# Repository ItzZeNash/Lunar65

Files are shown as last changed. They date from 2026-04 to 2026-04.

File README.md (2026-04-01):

# Lunar65
A keyboard made for personal use and sounds good, as I dont have a keyboard. 65% for optimal usability.
Render/Image

Images of Schem And PCB



# Build Guide










| No | Name | Spec | Quantity |
| ----- | ----- | ----- | ----- |
| 1 | Aluminum case | Aluminum | 1 |
| 2 | Main PCB | Hotswap socket compatible, 1.6 mm thick | 1 |
| 3 | Plate | Polycarbonate, 1.5mm thick | 1 |
| 4 | PCB foam | Poron, 3mm thick | 1 |
| 5 | Switch foam | Polyethylene or Poron, 0.5mm thick | 1 |
| 6 | Case foam | Poron, 1.5mm thick | 1 |
| 7 | Socket foam | Poron, 1.5mm thick | 1 |
| 8 | O-ring | AS568-264-VMQ-A30 | 1 |
| 9 | USB-C daughter board | [Unified Daughterboard C3](https://github.com/ai03-2725/Unified-Daughterboard) | 1 |
| 10 | JST cable | JST-SH, 4pin, double-side female connector, reverse direction, 10cm | 1 |
| 11 | Screws | m2 4mm, for USB-C daughter board | 4 |
| 12 | Rubber feet(Bumpons) | 3M SJ5302, diameter 8mm, height 2mm | 4 |

### Parts
| Name | Spec | Quantity |
| ----- | ----- | ----- |
| Key switch | CherryMX compatible key switch, 5pins(recommended) | 67 |
| Keycap | CherryMX compatible keycap, 1.75U Shift key(required) | 67 |
| Stabilizer | Durock V2, etc | 6.25U * 1set and 2U * 3set |
| USB cable | The connector on the keyboard side must be USB-C | 1 |
| Grease for lubrication | Krytox 205g0(recommended) | a few grams |

## Assembly Instructions
1. **Attaching rubber feet**  
   Rubber feet
   First attach the rubber feet to the aluminum case so that the bottom of the aluminum case is not scratched.  
   Attach the rubber feet according to the engraved circle on the four corners of the back of the aluminum case.  

1. **Pasting socket foam**  
   Pasting socket foam
   Pasting socket foam is difficult and cannot be redone.  
   There are two methods: one is to paste the entire surface and the other is to paste only a portion of the surface.  
   
   **Practice**  
   First, practice several times without peeling off the release paper on the adhesive surface.  
   Pasting socket foam
   Place the socket foam on a flat surface with the adhesive surface facing up.  
   Straighten any bent or floating parts.  
   Pasting socket foam
   Hold the four corners with the back side (part mounting surface) of the main PCB facing down.  
   Look at the main PCB from directly above, align the notch of the mount post with the main PCB, slowly put it on the foam.  

   **When pasting the entire surface**  
   Peel off the release paper on the socket foam, and paste the main PCB and socket foam according to the procedure you practiced.  
   Once pasted, it cannot be removed cleanly, so recommend not removing it, even if it is slightly displaced.  
   (even if it can be removed, the socket foam will be stretched and the position will not match)  
   
   **When pasting only a part**  
   Peel off only a part of the release paper and paste it.  
   The area to peel off is about 10 square mm per place, and the place to peel off is about 7-8 places where the width is not narrow.  
   Cut a part of the release paper with scissors and paste the main PCB and socket foam according to the procedure you practiced.

1. **Assembling the stabilizers**  
   Please refer to [this YouTube video](https://www.youtube.com/watch?v=-vhpHjlkRgQ).  
   Apply a little thick grease to the outside of the stem and the inside of the housing.  
   Insert the stem into the housing.  
   Apply a little thick grease from the tip of the wire to the part that bends at a right angle.  
   Insert the wire into the stem and fit the wire into the housing.  

1. **Installing stabilizers**  
   Installing stabilizers
   First, insert the side without screw holes into the larger stabilizer mounting holes on the main PCB.  
   Next, screw the side with screw holes from the back side of the main PCB.  
   Make sure that the stabilizer housing is not lifted off the main PCB and that there is no rattling.  

1. **Placing switch foam**  
   Placing switch foam
   Place the switch foam on the main PCB.  
   Slide the switch foam so that it is under the stabilizer wires.  

1. **Placing PCB foam**  
   Placing PCB foam
   Place PCB foam on the main PCB in line with the stabilizer position.  

1. **Placing plate**
   Placing plate
   Place the plate on the PCB foam, aligning it with the hole in the key switches.  

1. **Lubricating key switches**  
   Although not required, it is highly recommended to lubricate the key switches to improve the typing feels and sounds.  
   Please refer to [this YouTube video](https://www.youtube.com/watch?v=44Wv4OGdmu4).  

1. **Installing key switches**  
   Installing key switches
   Check that the holes in the switch foam align with the key switch pin holes on the main PCB.  
   Check that the pins of the key switch are straight and insert the key switch into the main PCB from the top of the plate.  
   (Be careful not to insert at an angle, as this may break the pins or damage the sockets)  
   Make sure that there are no gaps between the plate and the key switches, and between the key switches and the main PCB, viewed from the side, and that they are evenly installed.  

1. **Installing O-ring**  
   Install O-ring between main PCB and plate.  
   Installing O-ring
   
   Around the backspace and spacebar keys, pass the O-ring through the top surface of the stabilizer, aligning it with the notch in the plate.  
   If the O-ring cannot be secured to the top of the stabilizer, proceed as is once it is in place, as it can be adjusted when the main PCB is installed in the case.  
   Make sure there is no gap and bend between the main PCB, O-ring and plate when viewed from the side.  

1. **Connecting JST cable to USB-C daughter board**  
   Connecting JST cable to USB-C daughter board
   Connect JST cable to USB-C daughter board.  
   Connecting JST cable to USB-C daughter board
   Since JST cable connectors have front and back sides, refer to the photo and insert the connector with the side with no exposed terminals facing up.    

1. **Installing USB-C daughter board**  
   Installing USB-C daughter board
   With the surface of the USB-C daughter board (the side where the components are mounted) facing up, screw it into the center back of the aluminum case with four m2 4mm screws.  
   Grab the screws with tweezers to make it easier to screw them in.  

1. **Installing case foam**  
   Installing case foam
   Align the posts inside the aluminum case with the notches in the case foam, and put the case foam inside the aluminum case.    
   Pull the JST cable through the cutout in the case foam.  

1. **Connecting JST cable tom main PCB**  
   Connecting JST cable tom main PCB
   Insert the JST cable connector into the JST connector (beige color) on the back of the main PCB.  
   Connecting JST cable tom main PCB
   Since JST cable connectors have front and back sides, refer to the photo and insert the connector with the side with no exposed terminals facing up.    

1. **Installing main PCB to aluminum case**  
   Installing main PCB to aluminum case
   With the back side of the main PCB slightly raised, pass the blocker of the aluminum case between the blocker of the main PCB and the O-ring.    
   Lift the entire main PCB slightly and put the O-ring on the front side of the main PCB over the post on the front side of the aluminum case (not visible).  
   Gently push the main PCB down until the O-ring lightly touches the post on the aluminum case (not visible).  
   O-ring and back space
   Make sure the O-ring is not rolled up and coming out of  the plate.  

1. **Installing keycaps**  
   Installing keycaps
   Installing the keycaps to the key switches.  

1. **Connecting USB cable**  
   Connecting USB cable
   Connect your USB cable to the keyboard and PC and now it is completed.

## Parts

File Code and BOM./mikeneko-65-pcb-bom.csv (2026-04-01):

Designator | Comment | Footprint | LCSC Part #
C1 C2 C3 | 0.1u | Capacitor_SMD:C_0805_2012Metric | C49678
C4 | 10u | Capacitor_SMD:C_0805_2012Metric | C15850
C5 C6 | 22p | Capacitor_SMD:C_0805_2012Metric | C1804
C7 | 1u | Capacitor_SMD:C_0805_2012Metric | C28323
D1 D2 D3 D4 D5 D6 D7 D8 D9 D10 D11 D12 D13 D14 D15 D16 D17 D18 D19 D20 D21 D22 D23 D24 D25 D26 D27 D28 D29 D30 D31 D32 D33 D34 D35 D36 D37 D38 D39 D40 D41 D42 D43 D44 D45 D46 D47 D48 D49 D50 D51 D52 D53 D54 D55 D56 D57 D58 D59 D60 D61 D62 D63 D64 D65 D66 D67 | 1N4148 | Diode_SMD:D_SOD-123 | C81598
F1 | 500mA | Fuse:Fuse_1206_3216Metric | C70076
J1 | JST SH 4-pin | Connector_JST:JST_SH_SM04B-SRSS-TB_1x04-1MP_P1.00mm_Horizontal | C145956
MX1 MX2 MX3 MX4 MX5 MX6 MX7 MX8 MX9 MX10 MX11 MX12 MX13 MX15 MX17 MX18 MX19 MX20 MX21 MX22 MX23 MX24 MX25 MX26 MX27 MX28 MX30 MX32 MX33 MX34 MX35 MX36 MX37 MX38 MX39 MX40 MX41 MX42 MX44 MX46 MX47 MX48 MX49 MX50 MX51 MX52 MX53 MX54 MX55 MX57 MX58 MX65 MX66 MX67 | 1u | MX_Only:MXOnly-1U-Hotswap | C2803348
MX14 | 2u | MX_Only:MXOnly-2U-Hotswap | C2803348
MX16 MX29 | 1.5u | MX_Only:MXOnly-1.5U-Hotswap | C2803348
MX31 MX56 | 1.75u | MX_Only:MXOnly-1.75U-Hotswap | C2803348
MX43 MX45 | 2.25u | MX_Only:MXOnly-2.25U-Hotswap | C2803348
MX59 MX60 MX61 MX63 MX64 | 1.25u | MX_Only:MXOnly-1.25U-Hotswap | C2803348
MX62 | 6.25u | MX_Only:MXOnly-6.25U-Hotswap-ReversedStabilizers | C2803348
R1 R4 | 10k | Resistor_SMD:R_0805_2012Metric | C17414
R2 R3 | 22 | Resistor_SMD:R_0805_2012Metric | C17561
SW1 | Reset | Button_Switch_SMD:SW_SPST_TL3342 | C318884
U1 | SRV05-4 | Package_TO_SOT_SMD:SOT-23-6 | C85364
U2 | ATmega32U4-MUR | Package_DFN_QFN:QFN-44-1EP_7x7mm_P0.5mm_EP5.2x5.2mm | C45874
Y1 | 16MHz | Crystal:Crystal_SMD_3225-4Pin_3.2x2.5mm | C13738

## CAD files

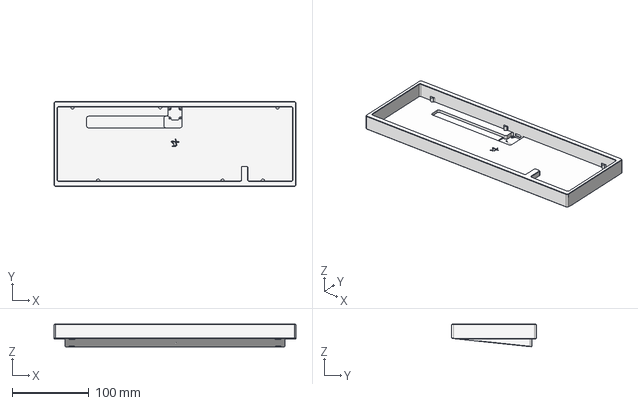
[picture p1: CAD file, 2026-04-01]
Case Files/セ-65-case.step
314.8 x 110.2 x 29.4 mm

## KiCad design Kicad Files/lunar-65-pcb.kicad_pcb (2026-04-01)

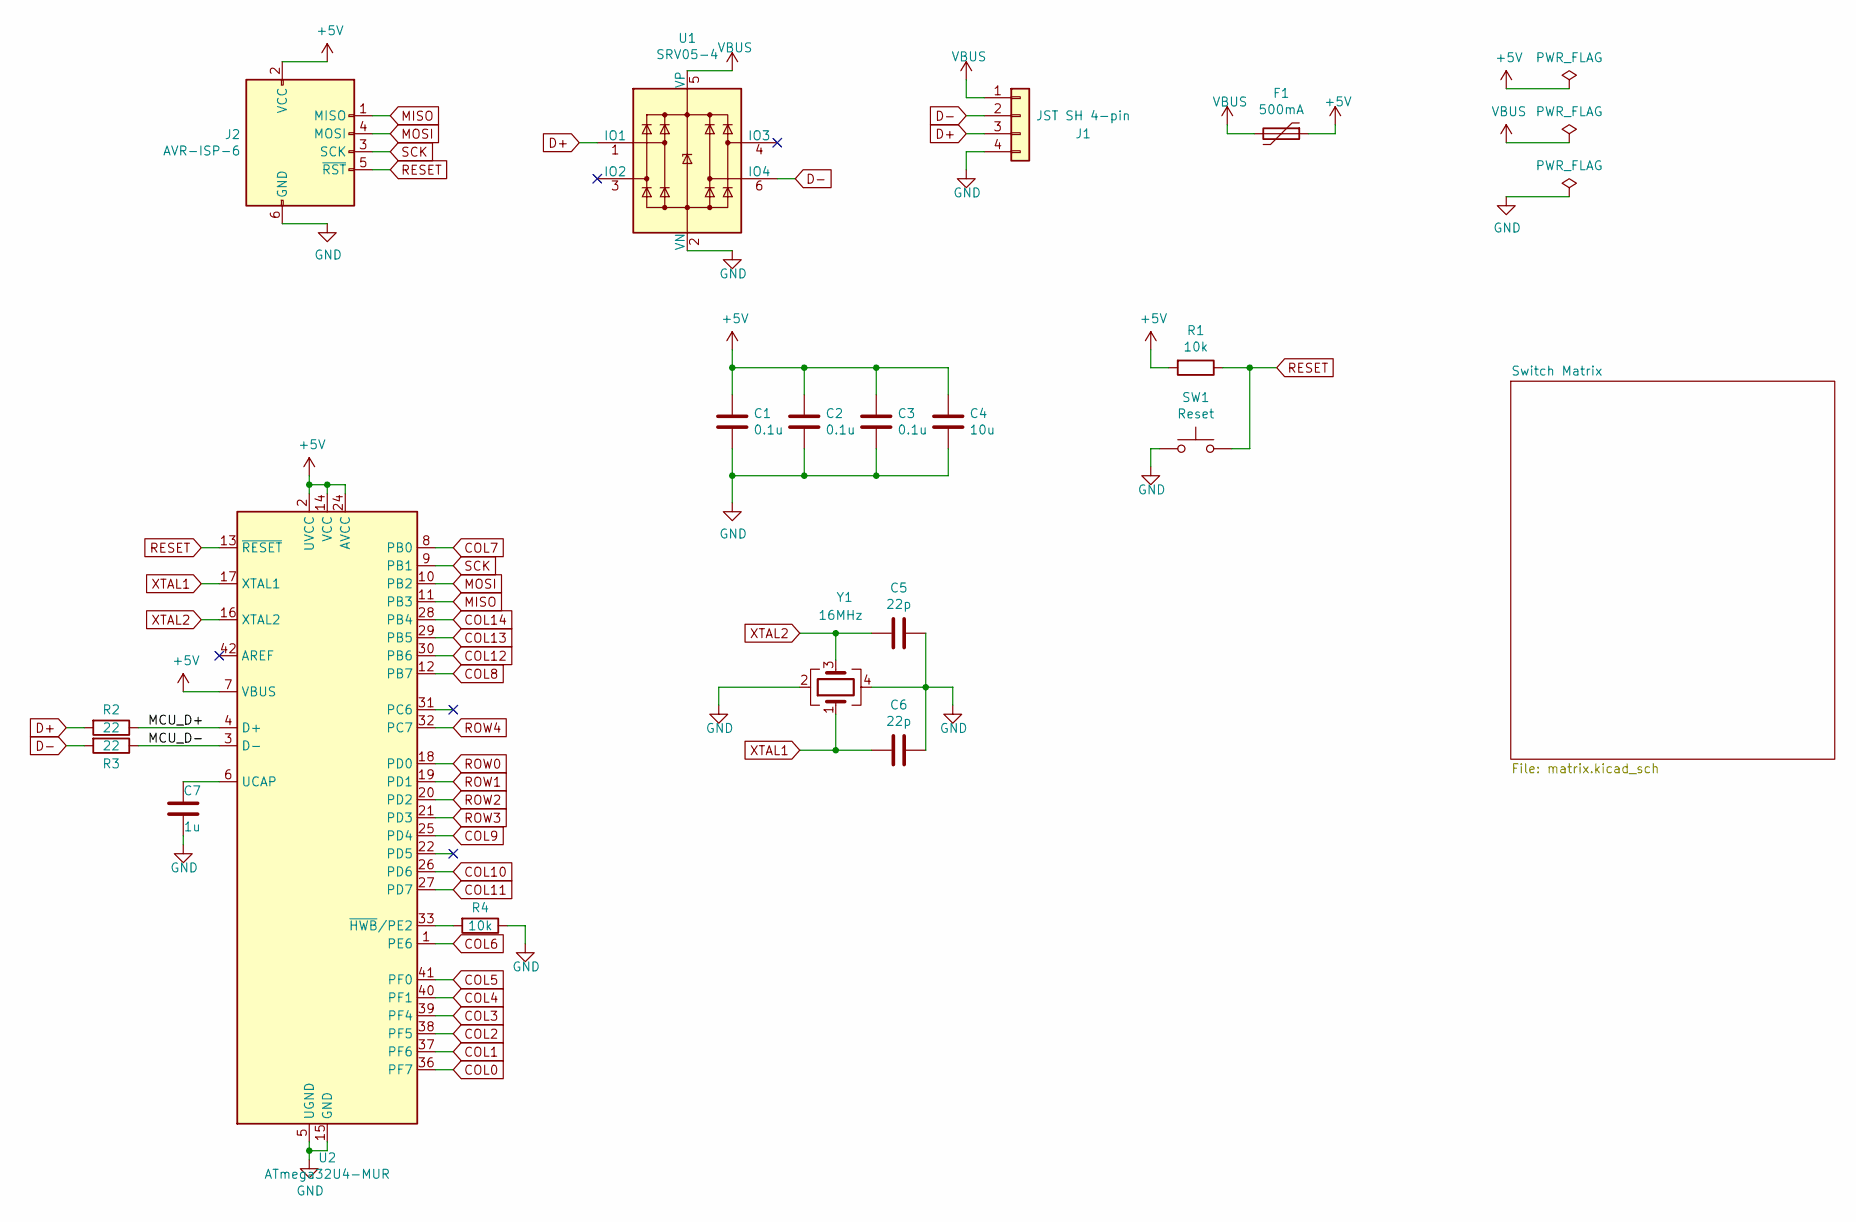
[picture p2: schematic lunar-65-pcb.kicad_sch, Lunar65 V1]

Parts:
C1, C2, C3: 0.1u; C_0805_2012Metric; LCSC Part # C49678
C4: 10u; C_0805_2012Metric; LCSC Part # C15850
C5, C6: 22p; C_0805_2012Metric; LCSC Part # C1804
C7: 1u; C_0805_2012Metric; LCSC Part # C28323
F1: 500mA; Fuse_1206_3216Metric; LCSC Part # C70076
J1: JST SH 4-pin; JST_SH_SM04B-SRSS-TB_1x04-1MP_P1.00mm_Horizontal; LCSC Part # C145956
J2: AVR-ISP-6; ISP
R1, R4: 10k; R_0805_2012Metric; LCSC Part # C17414
R2, R3: 22; R_0805_2012Metric; LCSC Part # C17561
SW1: Reset; SW_SPST_TL3342; LCSC Part # C318884
U1: SRV05-4; SOT-23-6; LCSC Part # C85364
U2: ATmega32U4-MUR; QFN-44-1EP_7x7mm_P0.5mm_EP5.2x5.2mm; LCSC Part # C45874
Y1: 16MHz; Crystal_SMD_3225-4Pin_3.2x2.5mm; LCSC Part # C13738

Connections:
+5V: C1.1, C2.1, C3.1, C4.1, F1.1, J2.2 (VCC), R1.2, U2.2 (UVCC), U2.7 (VBUS), U2.14 (VCC), U2.24 (AVCC), U2.34 (VCC), U2.44 (AVCC)
/MCU_D+: R2.1, U2.4 (D+)
/MCU_D-: R3.1, U2.3 (D-)
COL0: U2.36 (PF7); also elsewhere on the board
COL1: U2.37 (PF6); also elsewhere on the board
COL2: U2.38 (PF5); also elsewhere on the board
COL3: U2.39 (PF4); also elsewhere on the board
COL4: U2.40 (PF1); also elsewhere on the board
COL5: U2.41 (PF0); also elsewhere on the board
COL6: U2.1 (PE6); also elsewhere on the board
COL7: U2.8 (PB0); also elsewhere on the board
COL8: U2.12 (PB7); also elsewhere on the board
COL9: U2.25 (PD4); also elsewhere on the board
COL10: U2.26 (PD6); also elsewhere on the board
COL11: U2.27 (PD7); also elsewhere on the board
COL12: U2.30 (PB6); also elsewhere on the board
COL13: U2.29 (PB5); also elsewhere on the board
COL14: U2.28 (PB4); also elsewhere on the board
D+: J1.3, R2.2, U1.1 (IO1)
D-: J1.2, R3.2, U1.6 (IO4)
GND: C1.2, C2.2, C3.2, C4.2, C5.1, C6.1, C7.2, J1.4, J2.6 (GND), R4.1, SW1.1, U1.2 (VN), U2.5 (UGND), U2.15 (GND), U2.23 (GND), U2.35 (GND), U2.43 (GND), U2.45 (GND), Y1.2, Y1.4
MISO: J2.1 (MISO), U2.11 (PB3)
MOSI: J2.4 (MOSI), U2.10 (PB2)
unnamed: C7.1, U2.6 (UCAP)
unnamed: R4.2, U2.33 (~HWB/PE2)
RESET: J2.5 (~RST), R1.1, SW1.2, U2.13 (~RESET)
ROW0: U2.18 (PD0); also elsewhere on the board
ROW1: U2.19 (PD1); also elsewhere on the board
ROW2: U2.20 (PD2); also elsewhere on the board
ROW3: U2.21 (PD3); also elsewhere on the board
ROW4: U2.32 (PC7); also elsewhere on the board
SCK: J2.3 (SCK), U2.9 (PB1)
VBUS: F1.2, J1.1, U1.5 (VP)
XTAL1: C6.2, U2.17 (XTAL1), Y1.1
XTAL2: C5.2, U2.16 (XTAL2), Y1.3

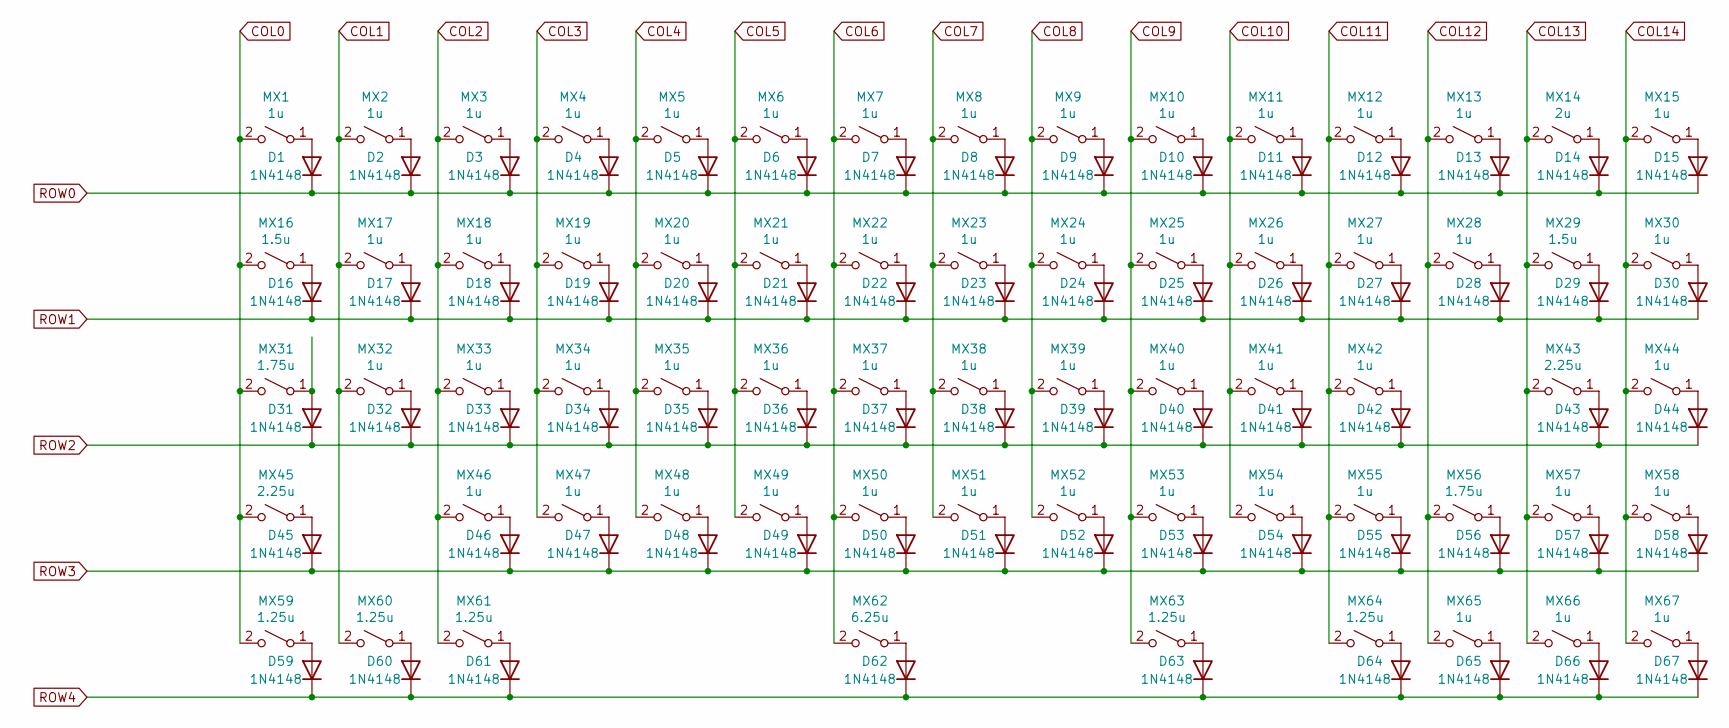
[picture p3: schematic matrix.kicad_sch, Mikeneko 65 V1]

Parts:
D1, D2, D3, D4, D5, D6, D7, D8, D9, D10, D11, D12, D13, D14, D15, D16, D17, D18, D19, D20, D21, D22, D23, D24, D25, D26, D27, D28, D29, D30, D31, D32, D33, D34, D35, D36, D37, D38, D39, D40, D41, D42, D43, D44, D45, D46, D47, D48, D49, D50, D51, D52, D53, D54, D55, D56, D57, D58, D59, D60, D61, D62, D63, D64, D65, D66, D67: 1N4148; D_SOD-123; LCSC Part # C81598
MX1, MX2, MX3, MX4, MX5, MX6, MX7, MX8, MX9, MX10, MX11, MX12, MX13, MX15, MX17, MX18, MX19, MX20, MX21, MX22, MX23, MX24, MX25, MX26, MX27, MX28, MX30, MX32, MX33, MX34, MX35, MX36, MX37, MX38, MX39, MX40, MX41, MX42, MX44, MX46, MX47, MX48, MX49, MX50, MX51, MX52, MX53, MX54, MX55, MX57, MX58, MX65, MX66, MX67: 1u; MXOnly-1U-Hotswap; LCSC Part # C2803348
MX14: 2u; MXOnly-2U-Hotswap; LCSC Part # C2803348
MX16, MX29: 1.5u; MXOnly-1.5U-Hotswap; LCSC Part # C2803348
MX31, MX56: 1.75u; MXOnly-1.75U-Hotswap; LCSC Part # C2803348
MX43, MX45: 2.25u; MXOnly-2.25U-Hotswap; LCSC Part # C2803348
MX59, MX60, MX61, MX63, MX64: 1.25u; MXOnly-1.25U-Hotswap; LCSC Part # C2803348
MX62: 6.25u; MXOnly-6.25U-Hotswap-ReversedStabilizers; LCSC Part # C2803348

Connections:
COL0: MX1.2 (B), MX16.2 (B), MX31.2 (B), MX45.2 (B), MX59.2 (B); also elsewhere on the board
COL1: MX2.2 (B), MX17.2 (B), MX32.2 (B), MX60.2 (B); also elsewhere on the board
COL2: MX3.2 (B), MX18.2 (B), MX33.2 (B), MX46.2 (B), MX61.2 (B); also elsewhere on the board
COL3: MX4.2 (B), MX19.2 (B), MX34.2 (B), MX47.2 (B); also elsewhere on the board
COL4: MX5.2 (B), MX20.2 (B), MX35.2 (B), MX48.2 (B); also elsewhere on the board
COL5: MX6.2 (B), MX21.2 (B), MX36.2 (B), MX49.2 (B); also elsewhere on the board
COL6: MX7.2 (B), MX22.2 (B), MX37.2 (B), MX50.2 (B), MX62.2 (B); also elsewhere on the board
COL7: MX8.2 (B), MX23.2 (B), MX38.2 (B), MX51.2 (B); also elsewhere on the board
COL8: MX9.2 (B), MX24.2 (B), MX39.2 (B), MX52.2 (B); also elsewhere on the board
COL9: MX10.2 (B), MX25.2 (B), MX40.2 (B), MX53.2 (B), MX63.2 (B); also elsewhere on the board
COL10: MX11.2 (B), MX26.2 (B), MX41.2 (B), MX54.2 (B); also elsewhere on the board
COL11: MX12.2 (B), MX27.2 (B), MX42.2 (B), MX55.2 (B), MX64.2 (B); also elsewhere on the board
COL12: MX13.2 (B), MX28.2 (B), MX56.2 (B), MX65.2 (B); also elsewhere on the board
COL13: MX14.2 (B), MX29.2 (B), MX43.2 (B), MX57.2 (B), MX66.2 (B); also elsewhere on the board
COL14: MX15.2 (B), MX30.2 (B), MX44.2 (B), MX58.2 (B), MX67.2 (B); also elsewhere on the board
unnamed: D1.2 (A), MX1.1 (A)
unnamed: D2.2 (A), MX2.1 (A)
unnamed: D3.2 (A), MX3.1 (A)
unnamed: D4.2 (A), MX4.1 (A)
unnamed: D5.2 (A), MX5.1 (A)
unnamed: D6.2 (A), MX6.1 (A)
unnamed: D7.2 (A), MX7.1 (A)
unnamed: D8.2 (A), MX8.1 (A)
unnamed: D9.2 (A), MX9.1 (A)
unnamed: D10.2 (A), MX10.1 (A)
unnamed: D11.2 (A), MX11.1 (A)
unnamed: D12.2 (A), MX12.1 (A)
unnamed: D13.2 (A), MX13.1 (A)
unnamed: D14.2 (A), MX14.1 (A)
unnamed: D15.2 (A), MX15.1 (A)
unnamed: D16.2 (A), MX16.1 (A)
unnamed: D17.2 (A), MX17.1 (A)
unnamed: D18.2 (A), MX18.1 (A)
unnamed: D19.2 (A), MX19.1 (A)
unnamed: D20.2 (A), MX20.1 (A)
unnamed: D21.2 (A), MX21.1 (A)
unnamed: D22.2 (A), MX22.1 (A)
unnamed: D23.2 (A), MX23.1 (A)
unnamed: D24.2 (A), MX24.1 (A)
unnamed: D25.2 (A), MX25.1 (A)
unnamed: D26.2 (A), MX26.1 (A)
unnamed: D27.2 (A), MX27.1 (A)
unnamed: D28.2 (A), MX28.1 (A)
unnamed: D29.2 (A), MX29.1 (A)
unnamed: D30.2 (A), MX30.1 (A)
unnamed: D31.2 (A), MX31.1 (A)
unnamed: D32.2 (A), MX32.1 (A)
unnamed: D33.2 (A), MX33.1 (A)
unnamed: D34.2 (A), MX34.1 (A)
unnamed: D35.2 (A), MX35.1 (A)
unnamed: D36.2 (A), MX36.1 (A)
unnamed: D37.2 (A), MX37.1 (A)
unnamed: D38.2 (A), MX38.1 (A)
unnamed: D39.2 (A), MX39.1 (A)
unnamed: D40.2 (A), MX40.1 (A)
unnamed: D41.2 (A), MX41.1 (A)
unnamed: D42.2 (A), MX42.1 (A)
unnamed: D43.2 (A), MX43.1 (A)
unnamed: D44.2 (A), MX44.1 (A)
unnamed: D45.2 (A), MX45.1 (A)
unnamed: D46.2 (A), MX46.1 (A)
unnamed: D47.2 (A), MX47.1 (A)
unnamed: D48.2 (A), MX48.1 (A)
unnamed: D49.2 (A), MX49.1 (A)
unnamed: D50.2 (A), MX50.1 (A)
unnamed: D51.2 (A), MX51.1 (A)
unnamed: D52.2 (A), MX52.1 (A)
unnamed: D53.2 (A), MX53.1 (A)
unnamed: D54.2 (A), MX54.1 (A)
unnamed: D55.2 (A), MX55.1 (A)
unnamed: D56.2 (A), MX56.1 (A)
unnamed: D57.2 (A), MX57.1 (A)
unnamed: D58.2 (A), MX58.1 (A)
unnamed: D59.2 (A), MX59.1 (A)
unnamed: D60.2 (A), MX60.1 (A)
unnamed: D61.2 (A), MX61.1 (A)
unnamed: D62.2 (A), MX62.1 (A)
unnamed: D63.2 (A), MX63.1 (A)
unnamed: D64.2 (A), MX64.1 (A)
unnamed: D65.2 (A), MX65.1 (A)
unnamed: D66.2 (A), MX66.1 (A)
unnamed: D67.2 (A), MX67.1 (A)
ROW0: D1.1 (K), D2.1 (K), D3.1 (K), D4.1 (K), D5.1 (K), D6.1 (K), D7.1 (K), D8.1 (K), D9.1 (K), D10.1 (K), D11.1 (K), D12.1 (K), D13.1 (K), D14.1 (K), D15.1 (K); also elsewhere on the board
ROW1: D16.1 (K), D17.1 (K), D18.1 (K), D19.1 (K), D20.1 (K), D21.1 (K), D22.1 (K), D23.1 (K), D24.1 (K), D25.1 (K), D26.1 (K), D27.1 (K), D28.1 (K), D29.1 (K), D30.1 (K); also elsewhere on the board
ROW2: D31.1 (K), D32.1 (K), D33.1 (K), D34.1 (K), D35.1 (K), D36.1 (K), D37.1 (K), D38.1 (K), D39.1 (K), D40.1 (K), D41.1 (K), D42.1 (K), D43.1 (K), D44.1 (K); also elsewhere on the board
ROW3: D45.1 (K), D46.1 (K), D47.1 (K), D48.1 (K), D49.1 (K), D50.1 (K), D51.1 (K), D52.1 (K), D53.1 (K), D54.1 (K), D55.1 (K), D56.1 (K), D57.1 (K), D58.1 (K); also elsewhere on the board
ROW4: D59.1 (K), D60.1 (K), D61.1 (K), D62.1 (K), D63.1 (K), D64.1 (K), D65.1 (K), D66.1 (K), D67.1 (K); also elsewhere on the board

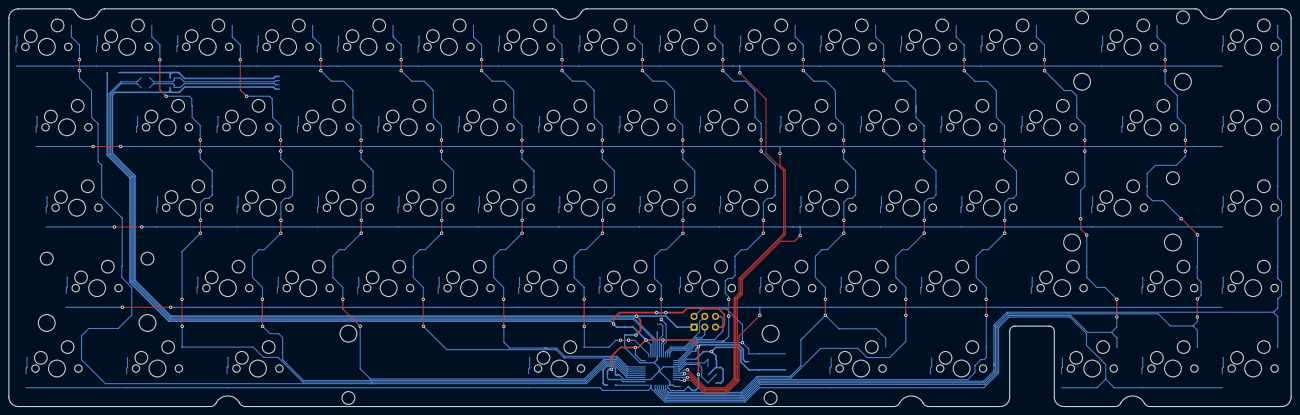
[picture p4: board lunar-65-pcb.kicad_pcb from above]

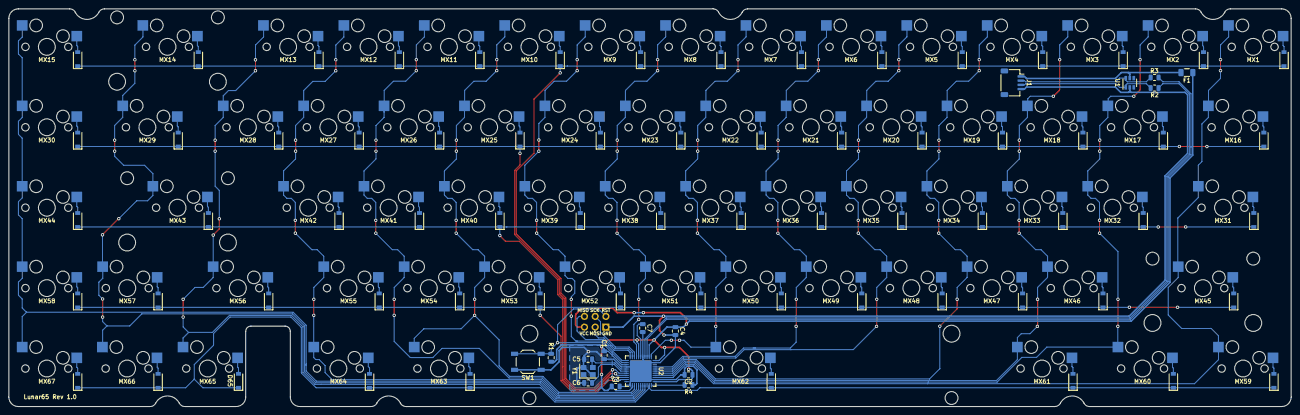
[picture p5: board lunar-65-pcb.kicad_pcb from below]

Board: 2 copper layers, 303.8 x 94.2 mm, 152 parts (84 on the bottom side), 102 nets.

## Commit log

2026-04-01 Update README with images of Lunar65 keyboard
    Added images of the keyboard and its schematics.
2026-04-01 Add build guide and assembly instructions to README
    Added a detailed build guide with parts list and assembly instructions.

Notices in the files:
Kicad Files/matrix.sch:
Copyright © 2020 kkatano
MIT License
